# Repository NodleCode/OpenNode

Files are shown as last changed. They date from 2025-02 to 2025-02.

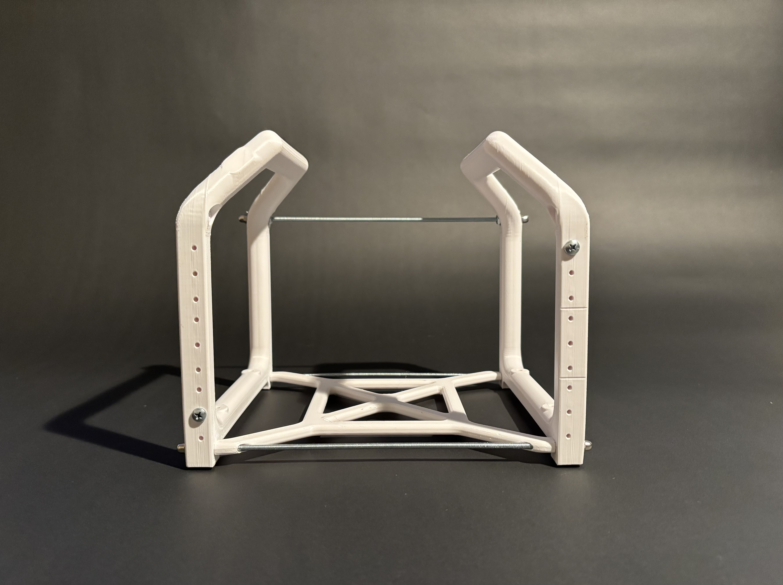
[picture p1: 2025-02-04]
Images/OpenNode_Prototype.jpg

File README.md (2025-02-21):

# The Open Node Project
Decentralized tools for humanity.

## Background
The Open Node Project enables anyone to deploy enterprise-grade, decentralized physical infrastructure. Starting with the best open-source, 3D-printable 3U+ 10-inch server rack design:



##Extension: 
Screenshot 2025-02-21 at 8 53 17 AM

## Projects supported
* The Open Node Rack + Extension
* Coming Soon... 

## BOM for ON-1 Frame
| Part | Units | Notes |
|---|---|---|
| ON-1 Frame | 2 | uses 113g filament |
| ON-1 Base Plate | 1 | |
| #8 UNC (~4MM) threaded Rod | 3 | Cut to 10.25 in (260mm) |
| #8 washers | 12 | |
| #8 Machine screw nuts | 12 | |
| M3x4x5 Heat set threaded inserts | 18 | [Amazon US Link](https://www.amazon.com/dp/B0BTYF2MMD?ref=ppx_yo2ov_dt_b_fed_asin_title) |
| M3x6 Thumb Screws | as needed | [Amazon US Link](https://www.amazon.com/dp/B0DBM1JJRJ?ref=ppx_yo2ov_dt_b_fed_asin_title) |
| or | | |
| #10 x 5/8 in self-tapping screws | as needed | |

## Print Instructions 
You need 2X Frames and 1X base Plate.

* Min bed size 250x250mm (printed on a Bambu P1S).
* Material: The reference files are printed with ASA Filaments (more durable and easier to print than ABS) but PLA or other materials works just fine.
* Supports set to Tree: Auto. 

Recommended orientation: 
Screenshot 2025-02-10 at 12 29 58 PM

## Assembly 

1. Print 2X Frames and 1X base plates 
2. Cut 3x metal rods to 10.25in (260mm) Lineman Pliers work well for cutting, but will requre filing on the ends to ensure the nuts fit (yes we know that is a rusty wood file)
Screenshot 2025-02-10 at 1 26 33 PM
Screenshot 2025-02-10 at 1 27 05 PM
3. Insert threaded rods with washer and and screw nuts onto the bottom side holes 
Screenshot 2025-02-10 at 1 27 49 PM
4. Slide the base plate on, followed by the other Frame piece 
Screenshot 2025-02-10 at 1 30 26 PM
5. Add washers and screw nuts, tighten down until the frame does not wiggle
Screenshot 2025-02-10 at 1 32 25 PM
6. Optional: you can add another threaded rod to the top rear of the rack for added strength
7. Optional: Add 4x adhesive Rubber Bumbers to the feet for a luxurious feel. Leave out if you are attaching the extender
8. Optional: Add M3x4x5 Heat set inserts with a dsoldering iron to support M3x6 metal thumb screws. If not use plastic self tapping screws (#8 worked for us in the US).  Highly recommend fun colored thumb screws:
Screenshot 2025-02-09 at 5 47 17 PM

## Extender Module: 


## CAD Files
https://cad.onshape.com/documents/316cd9ed33c458cd73b28ece/w/db9c7f5ecd3d8b58a5007c36/e/6799c84f86b383e823056bb1
Bambu Print Files
https://makerworld.com/en/models/1073247#profileId-1063589

More coming soon... 

ONlogo

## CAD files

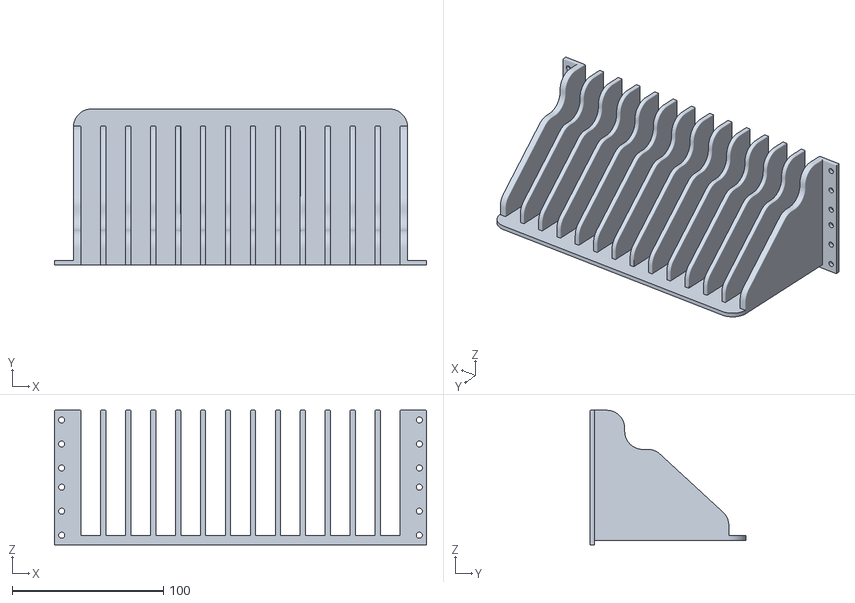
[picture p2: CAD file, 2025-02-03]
10in Rack Parts STLs/Smartphone holder - Part 1 (1).stl
246.0 x 103.2 x 89.0

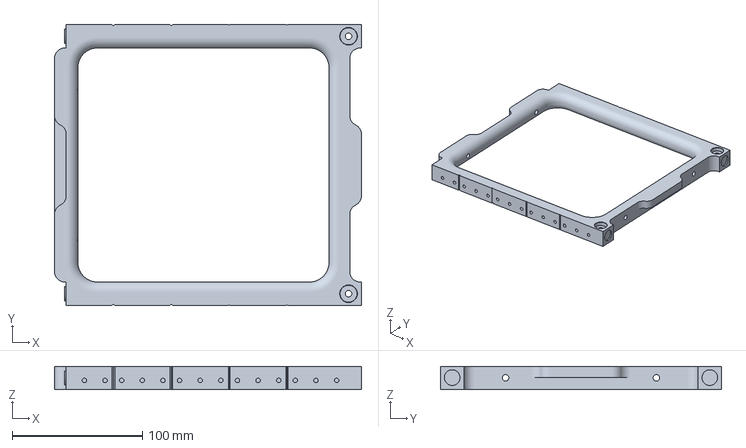
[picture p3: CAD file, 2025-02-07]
10in Server Rack Frame STLs/ON-1-extender.3mf
236.0 x 215.9 x 18.0 mm

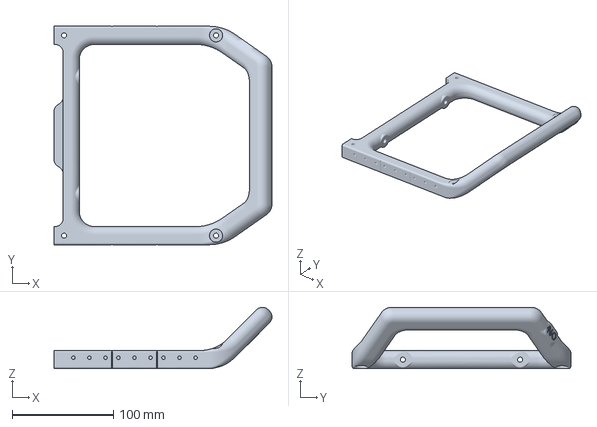
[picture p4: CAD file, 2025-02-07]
10in Server Rack Frame STLs/ON-1-3_Frame.3mf
215.4 x 215.9 x 60.6 mm

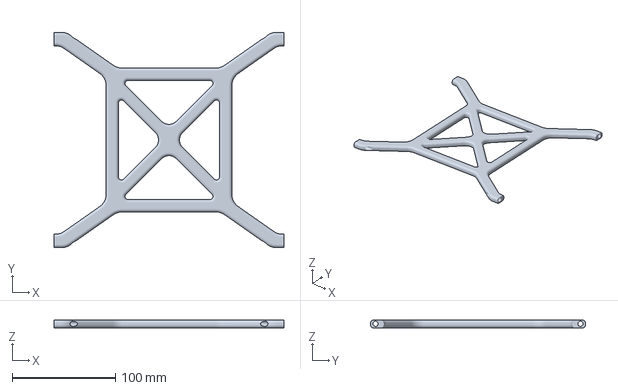
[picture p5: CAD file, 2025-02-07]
10in Server Rack Frame STLs/ON-1-base plate.3mf
222.2 x 207.9 x 7.50 mm

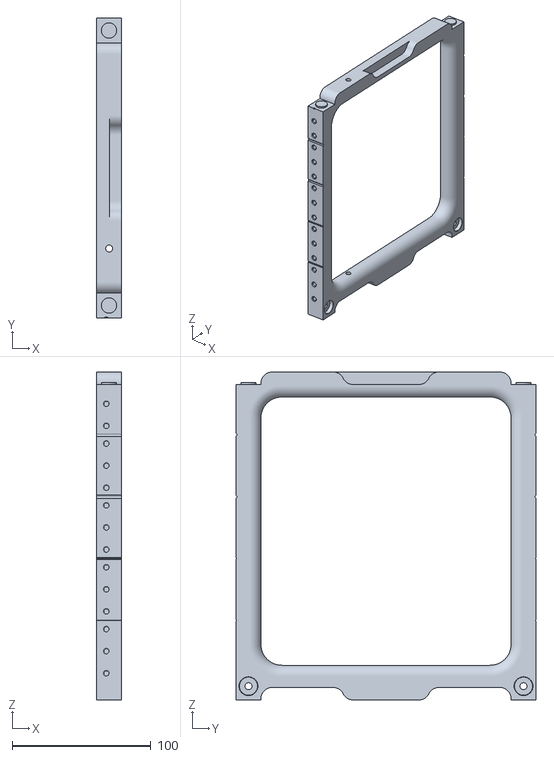
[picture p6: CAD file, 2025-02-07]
10in Server Rack Frame STLs/ON_1-5_Extender.stl
18.0 x 215.9 x 236.0

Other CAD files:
10in Server Rack Frame STLs/ON-1-5_Frame.gcode.3mf
10in Server Rack Frame STLs/ON-1-5_Frame.stl
10in Server Rack Frame STLs/ON-1-2_Extender.stl
10in Server Rack Frame STLs/ON-1_Base_Plate.stl

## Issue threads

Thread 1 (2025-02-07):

Additional Instructions

jainavgohel, 2025-02-07:
Would love to give this a shot but, it needs some more instructions. Specifically printer settings and min requirements, hardware requirements/links, and assembly instructions.

Additionally would love to see a parametric design for some of the pieces to allow for expandability.

garrettekinsman, 2025-02-10:
Updated, will be adding more tutorials as we announce software partners to this!
https://github.com/NodleCode/OpenNode/blob/main/README.md

Please share your experience and questions

Closed 2025-02-11.

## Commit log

2025-02-03 Added latest Files, organized folder
    [ON-1-3_Frame.stl, ON-1_Base_Plate.stl, ONframe 1-1.stl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]
2025-02-04 new extender STL
    [Extender - ON-1_Extender.stl, ON-1-1_Extender.stl]
2025-02-04 New STL
    [ON-1-3_Frame.stl, ON-1-4_Frame.stl]
2025-02-04 new files
    [ON-1-2_Extender.stl, ON-1-4_Frame.gcode.3mf]
2025-02-07 Updated screw holes on Rack + extender to support thread inserts
    [ON-1-3_Frame.3mf, ON-1-4_Frame.gcode.3mf, ON-1-4_Frame.stl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]
